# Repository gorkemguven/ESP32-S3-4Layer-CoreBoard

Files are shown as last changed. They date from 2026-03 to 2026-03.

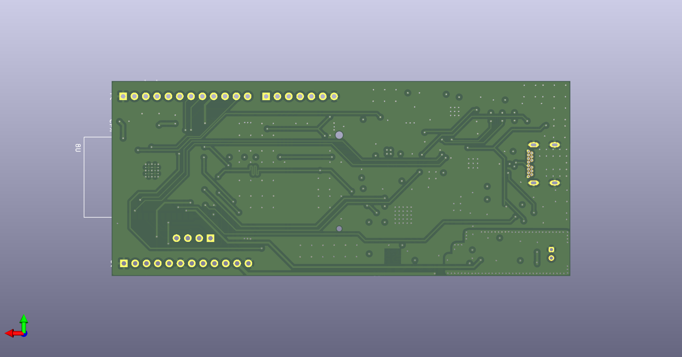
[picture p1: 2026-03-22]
Git_Hub_ESP32/3D_view/ESP-32_Design_Görkem_Güven_Bottom.png

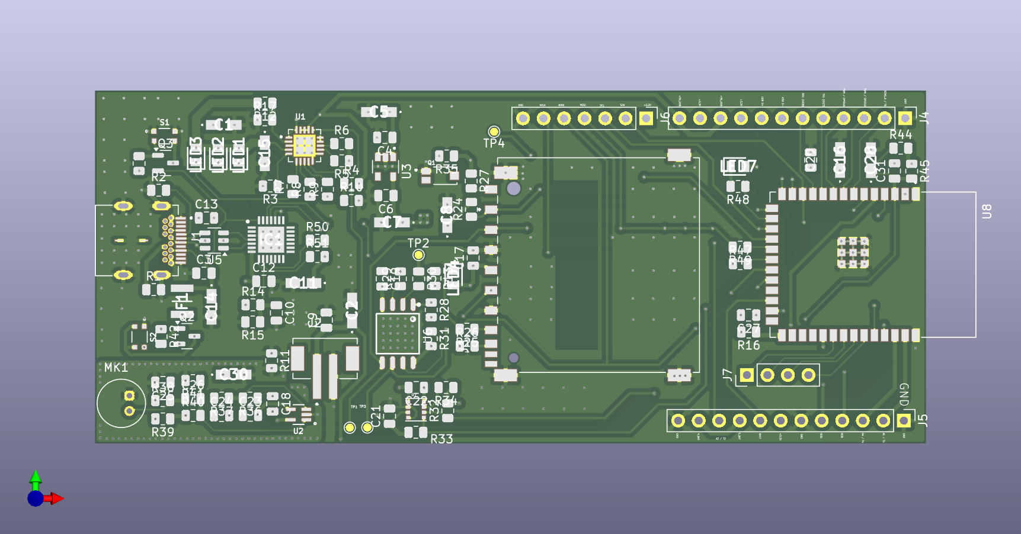
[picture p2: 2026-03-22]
Git_Hub_ESP32/3D_view/ESP-32_Design_Görkem_Güven_top.png

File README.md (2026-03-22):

# ESP32-S3 Multi-Sensor & High-Performance Development Board

## 1. Project Overview
This repository contains the complete hardware design for a high-performance development board powered by the **ESP32-S3-WROOM-1-N16R2** ($16\text{MB}$ Flash / $2\text{MB}$ PSRAM). This board is engineered for advanced IoT applications, environmental monitoring, and analog signal processing, featuring a robust power management system and high-fidelity sensor integration on a **4-layer PCB**.

---

## 2. Technical Specifications

### 2.1 Core System
*   **Microcontroller:** ESP32-S3 Dual-core Xtensa LX7 MCU, Wi-Fi & BLE 5.0.
*   **Memory:** $16\text{MB}$ Quad SPI Flash and $2\text{MB}$ PSRAM.
*   **External Storage:** 
    *   **MicroSD Card:** Integrated via SPI with dedicated pull-up resistors and decoupling.
    *   **External Flash:** **W25Q32JVSSIQ** ($32\text{M-bit}$) for redundant data logging or specific firmware needs.

### 2.2 Power Management & Battery
The power stage is designed for high reliability and seamless power transitions:
*   **Battery Charger:** **MCP73871** with System Power Path Management, allowing simultaneous battery charging and system operation.
*   **Protection:** VPCC (Voltage Proportional Charge Control) set to **$4.92\text{V}$** to prevent source collapse.
*   **Regulation:** **XC6220B331MR-G** high-current LDO providing a stable **$3.3\text{V}$** rail at up to **$1\text{A}$**.
*   **Input:** USB-C ($SS-52400-002$) with $5.1\text{k}\Omega$ resistors on CC lines for universal power delivery compatibility.
*   **Visual Indicators:** Dedicated LEDs for Charging (Red), Charge Complete (Green), and Power Good (Blue).

### 2.3 Sensors & Analog Input
*   **Environmental:** **BME280** (I2C) for high-precision pressure, temperature, and humidity sensing ($0\text{x}76$ address).
*   **Audio:** **MAX4466** low-noise microphone pre-amplifier with integrated $10\text{Hz}-20\text{kHz}$ bandwidth support.
*   **Light Sensing:** **TEMT6000X01** ambient light sensor for precise illuminance measurements.
*   **Signal Integrity:** Separate **Analog Ground (GNDA)** plane connected via a $0\Omega$ bridge to minimize digital switching noise in analog measurements.

### 2.4 Communication & Programming
*   **USB-to-UART:** **CP2102N** for high-speed serial communication (up to $3\text{Mbps}$).
*   **ESD Protection:** **USBLC6-2SC6** monolithic ESD protection on USB Data ($D+/D-$) and VBUS lines.
*   **Auto-Program Circuit:** Dual **BC817** NPN transistor logic for seamless "Auto-Reset" and "Boot" entry during firmware flashing.

---

## 3. PCB Design Details
*   **Layer Count:** 4 Layers (Signal - GND - VCC - Signal).
*   **Stack-up Strategy:** Internal Ground and Power planes to ensure low EMI and high power integrity for Wi-Fi/BT peaks.
*   **Impedance Control:** USB data lines are routed as **$90\Omega$** differential pairs.
*   **Passive Components:** Optimized decoupling using a mix of **X7R Ceramic** ($0.1\text{ }\mu\text{F}$ / $1\text{ }\mu\text{F}$) and **Low-ESR Tantalum** ($10\text{ }\mu\text{F}$ / $22\text{ }\mu\text{F}$) capacitors.

---

## 4. Repository Structure
*   `PROJE.kicad_sch`: Hierarchical schematic design files.
*   `PROJE.kicad_pcb`: 4-layer PCB layout with optimized trace routing.
*   `/docs`: Full schematic in PDF format and comprehensive Bill of Materials (BOM).

---

## 5. About the Author
**Görkem Güven**  
Electrical & Electronics Engineering Student  
*Muğla Sıtkı Koçman University*  
Expertise in Embedded Systems, Hardware Design, and Mixed-Signal PCB Layout.

---

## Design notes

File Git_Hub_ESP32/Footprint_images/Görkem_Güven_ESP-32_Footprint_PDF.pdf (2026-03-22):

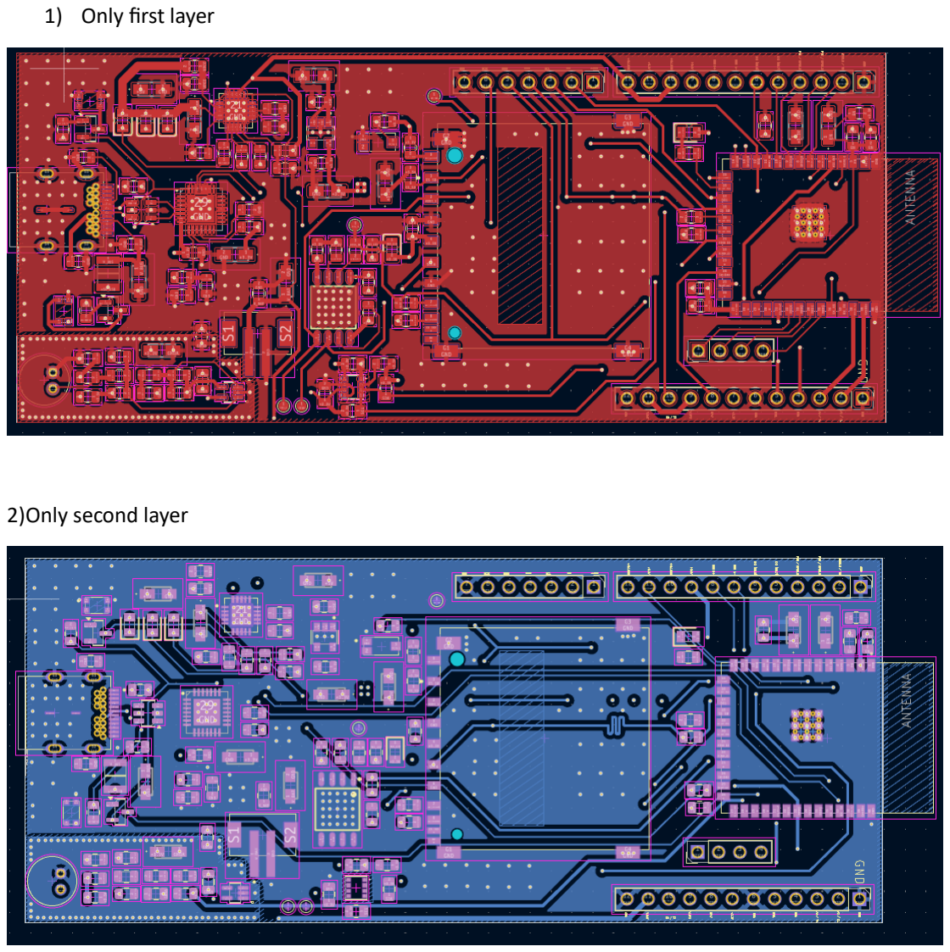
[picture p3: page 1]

1) Only first layer

2)Only second layer

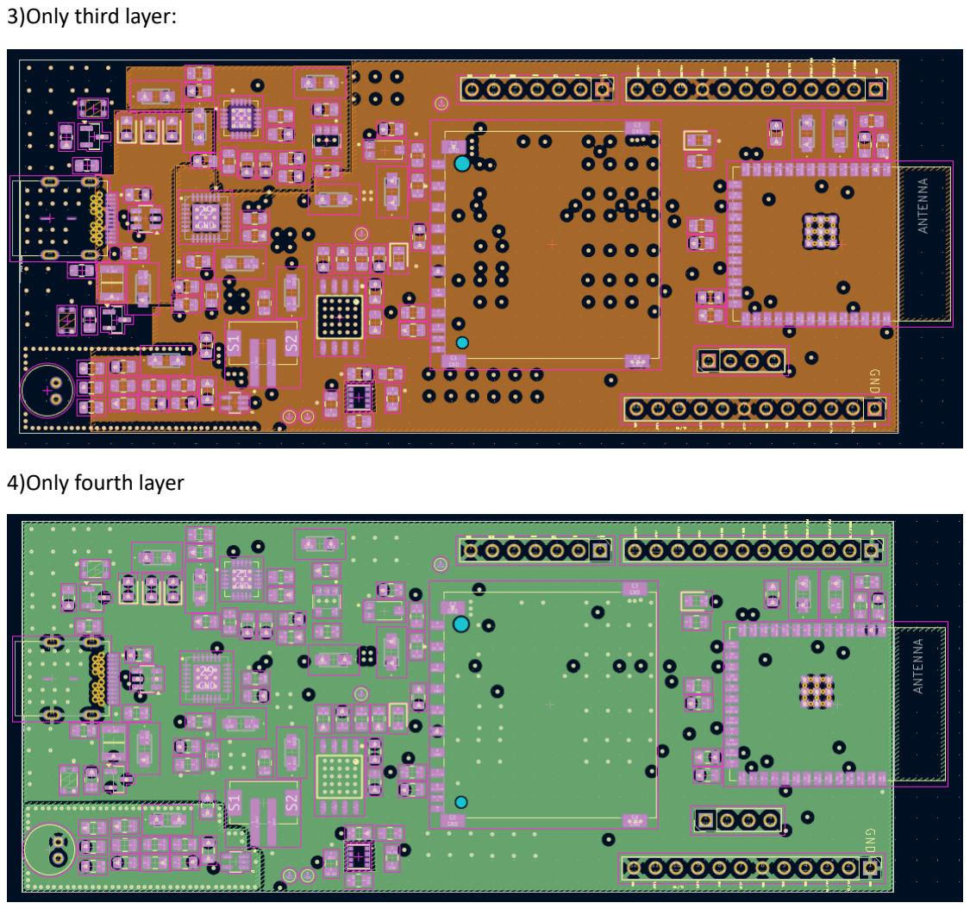
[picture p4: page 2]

3)Only third layer:

4)Only fourth layer

5)All layers is including

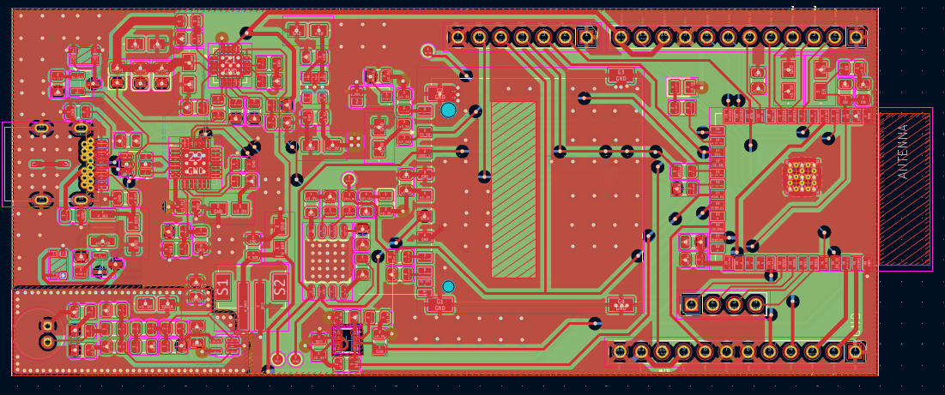
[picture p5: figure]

Görkem Güven

Muğla Sıtkı Koçman Uni.

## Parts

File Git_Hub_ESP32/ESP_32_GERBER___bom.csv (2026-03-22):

Designator | Footprint | Quantity | Value | LCSC Part #
C1, C14, C15, C2, C30, C5, C8 | T491A | 7 | 10uF
C10, C24, C31 | 0805 | 3 | 1uF
C11 | T491A | 1 | 4.7uF
C12, C13, C17, C18, C19, C21, C22, C25, C27, C29, C4, C6, C9 | 0805 | 13 | 100nF
C16, C7 | T491A | 2 | 22uF
C23 | 0805 | 1 | 100pF
C26 | 0805 | 1 | 10nF
C28 | T491A | 1 | 2.2u
C3 | 0805 | 1 | 0.1uF
F1 | FUSC3226X100N | 1 | 0ZCH0110AF2E
IC1 | QFN50P500X500X80-29N-D | 1 | CP2102N-A02-GQFN28R
J1 | BELFUSE_SS-52400-002 | 1 | SS-52400-002
J2 | JST_B2B-PH-SM4-TB | 1 | B2B-PH-SM4-TB
J3 | AMPHENOL_GSD090012SEU | 1 | GSD090012SEU
J4, J5 | PinHeader_1x12_P2.54mm_Vertical | 2 | Conn_01x12_Pin
J6 | PinHeader_1x07_P2.54mm_Vertical | 1 | Conn_01x07_Pin
J7 | PinHeader_1x04_P2.54mm_Vertical | 1 | Conn_01x04_Pin
LED1, LED7 | LEDC2012X120N | 2 | GREEN
LED2, LED4 | LEDC2012X120N | 2 | RED
LED3 | LEDC2012X120N | 1 | BLUE
MK1 | CUI_CMC-5042PF-AC | 1 | CMC-5042PF-AC
Q1 | TRANS_TEMT6000X01 | 1 | TEMT6000X01
Q2, Q3 | SOT-23 | 2 | BC817
R1, R2 | 0805 | 2 | 5.1k
R10, R4 | 0805 | 2 | 0 jumper
R11 | 0805 | 1 | 0 ohm
R12 | 0805 | 1 | 330k
R13, R48, R7, R8, R9 | 0805 | 5 | 470
R14 | 0805 | 1 | 22.1k
R15 | 0805 | 1 | 47.5k
R16, R24, R26, R27, R28, R29, R3, R31, R34, R35, R37, R42, R43, R44, R45, R50 | 0805 | 16 | 10k
R17 | 0805 | 1 | 110k
R25, R30, R47, R49 | 0805 | 4 | 50
R32, R33 | 0805 | 2 | 4.7k
R36 | 0805 | 1 | 100k
R38, R39, R5, R6 | 0805 | 4 | 2k
R40, R41 | 0805 | 2 | 1M
R51 | 0805 | 1 | 1k
S1 | SW_USLPT2819DT2TR | 1 | Boot
S2 | SW_USLPT2819DT2TR | 1 | Reset
TP1 | TestPoint_Pad_D1.0mm | 1 | Test_MOSI
TP2 | TestPoint_Pad_D1.0mm | 1 | Test_MISO
TP3 | TestPoint_Pad_D1.0mm | 1 | Test_SCLK
TP4 | TestPoint_Pad_D1.0mm | 1 | Test_CS_SD
U1 | QFN50P400X400X100-21N | 1 | MCP73871-2CAI_ML
U2 | SOT65P210X110-5N | 1 | MAX4466EXK
U3 | IC_XC8107AC20MR-G | 1 | XC6220B331MR-G
U5 | SOT-23-6 | 1 | USBLC6-2SC6
U6 | SOIC127P790X216-8N | 1 | W25Q32JVSSIQ
U7 | PSON65P250X250X100-8N | 1 | BME280
U8 | XCVR_ESP32-S3-WROOM-1-N16R2 | 1 | ESP32-S3-WROOM-1-N16R2
